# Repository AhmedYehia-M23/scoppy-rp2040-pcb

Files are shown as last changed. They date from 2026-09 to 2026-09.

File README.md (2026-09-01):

# Custom RP2040 Mixed-Signal Measurement PCB

**4-layer RP2040 hardware · KiCad · mixed-signal PCB layout · USB-C · hand assembly · hardware bring-up**

A university PCB-layout and hardware-bring-up project based on **professor-provided electrical schematics** for a custom RP2040 measurement board associated with the Scoppy oscilloscope ecosystem. My work was the **PCB implementation and physical hardware workflow**: placement, 4-layer stack-up and routing, fabrication preparation, hand assembly, bring-up and fault isolation.

| | |
|---|---|
| **Board** | 67 × 50 mm, 4 layers |
| **MCU** | RP2040 with W25Q128 QSPI flash |
| **Layout** | 64 footprints · 597 routed track segments · 58 vias |
| **Internal planes** | GND on In1.Cu · +3V3 on In2.Cu |
| **Academic context** | Materials and Manufacturing of Electronics · Summer Semester 2026 |

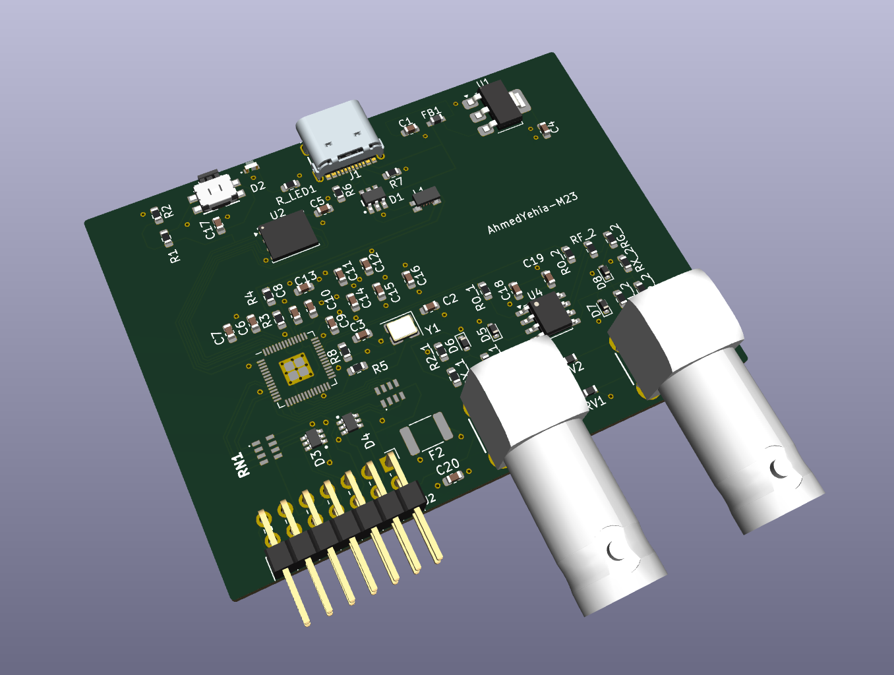
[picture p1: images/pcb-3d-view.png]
Scoppy RP2040 PCB 3D View


### Quick links

- [PCB layout source](hardware/Scoppy.kicad_pcb)
- [PCB layout image](images/pcb-layout.png)
- [Bring-up and debugging notes](docs/bring-up-and-debugging.md)
- [Source attribution](SOURCE_ATTRIBUTION.md)

> The electrical schematics and circuit/component-level design were supplied as course material. They are not redistributed here. The PCB placement, routing, assembly and bring-up documented in this repository are my project work.

## My contribution

- 4-layer PCB stack-up and physical implementation in KiCad
- complete component and footprint placement
- all PCB routing
- internal GND and +3V3 plane implementation
- mixed-signal physical-layout decisions
- board outline and physical organization
- design-rule checking and fabrication preparation
- complete hand assembly and soldering after fabrication
- board bring-up and electrical measurements
- USB-enumeration fault investigation
- power, continuity, USB, boot and clock checks
- root-cause isolation to incomplete RP2040 solder contact
- repair and restoration of USB enumeration

## PCB layout

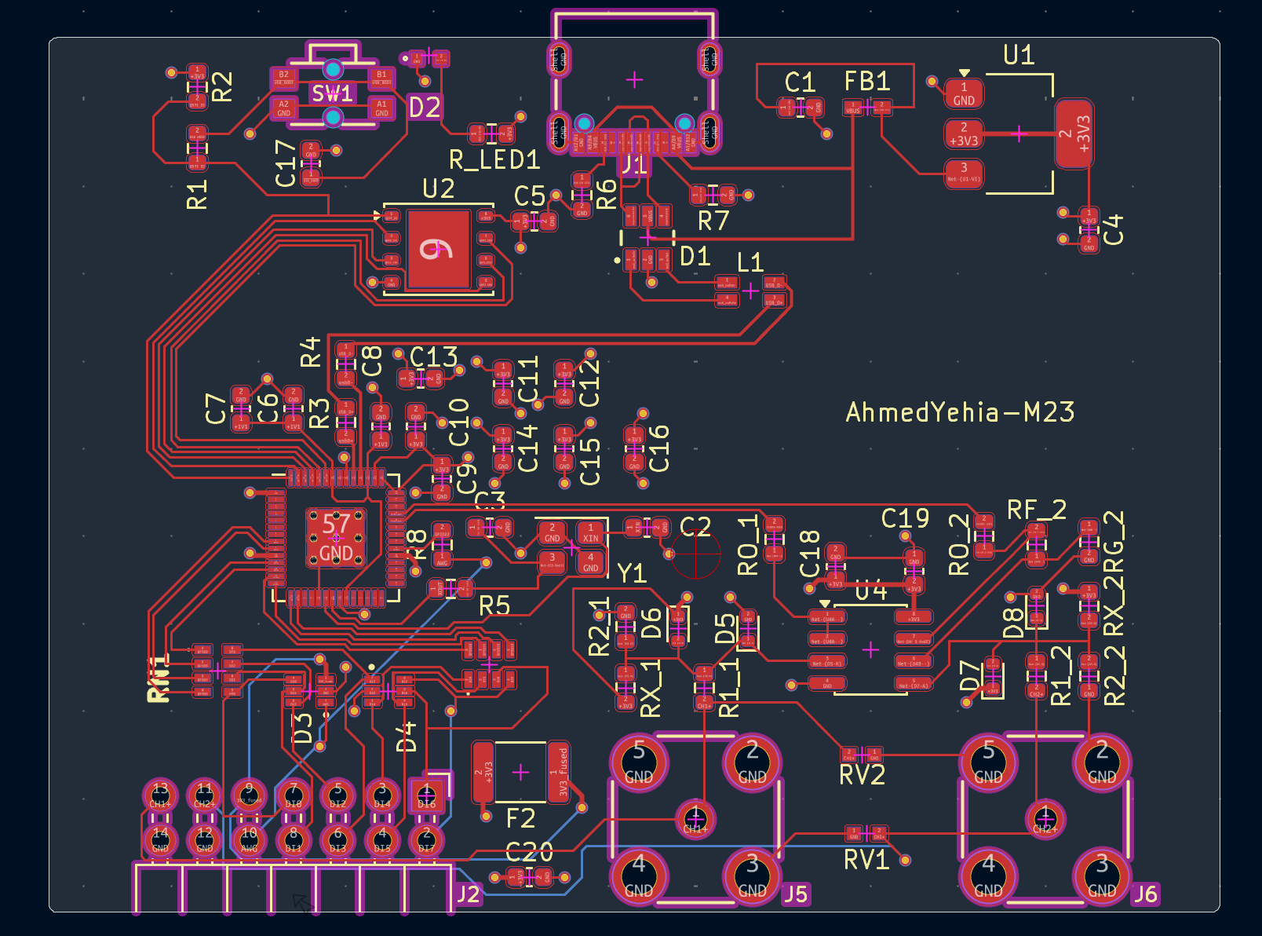
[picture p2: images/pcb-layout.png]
Scoppy RP2040 PCB Layout


## Architecture

Architecture

The supplied course design was organized into hierarchical **Power**, **Digital** and **Analog** schematic sheets. My task was to translate those circuit requirements into a manufacturable 4-layer PCB while managing placement, signal routing, return paths, power distribution and physical board constraints.

## Assembly and bring-up

After fabrication, I assembled and hand-soldered the complete board. The first assembled board powered up but failed to enumerate over USB, including BOOTSEL attempts.

The diagnostic sequence covered:

- 5 V, 3.3 V and RP2040 1.1 V rails
- RUN / BOOTSEL state
- external-flash related circuitry
- USB-C CC configuration
- D+ / D- continuity and short checks
- RP2040 grounding and exposed-pad contact
- 12 MHz crystal network
- physical MCU solder contact

The final root cause was incomplete electrical contact at the RP2040 package. Correcting the solder/contact defect **restored USB enumeration**.

The detailed check sequence and the boundary of the available evidence are documented in [`docs/bring-up-and-debugging.md`](docs/bring-up-and-debugging.md).

## Public project files

```text
hardware/
├── Scoppy.kicad_pro
├── Scoppy.kicad_pcb
├── fp-lib-table
└── LIB/
    └── footprints/
        └── DME_Template.pretty/

docs/
└── bring-up-and-debugging.md

images/
├── architecture.svg
├── pcb-layout.png
└── pcb-3d-view.png
```

Professor-provided schematic source and symbol/cache files are intentionally excluded from the public portfolio repository. Per-user KiCad state files, lock files, autosaves, backups and operating-system metadata are also excluded.

## Tools and skills

`KiCad` · `RP2040` · `4-Layer PCB Layout` · `Component Placement` · `Manual PCB Assembly & Soldering` · `Mixed-Signal PCB Routing` · `Internal Power/Ground Planes` · `USB-C` · `Hardware Bring-Up` · `Fault Isolation` · `Continuity & Voltage Measurement`

## Scoppy attribution

**Scoppy** is a separate project maintained by **fhdm-dev**. I did not develop the Scoppy Android application or its firmware. This repository presents my university PCB-layout, assembly and hardware-bring-up work and is not affiliated with or endorsed by the original Scoppy maintainers.

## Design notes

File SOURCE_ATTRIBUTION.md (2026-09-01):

# Source Attribution and Contribution Statement

## Electrical Schematics

The electrical schematics used for this university project were **provided by the professor as course/project material**. They defined the circuit and component-level electrical design that served as the input to the PCB-layout assignment.

The supplied material included the main schematic and hierarchical **Analog**, **Digital** and **Power** sheets.

I do **not** claim authorship of those electrical schematics. Their source files are intentionally **not redistributed in this public portfolio repository**.

## My Contribution

My individual engineering work on this project was the complete PCB implementation, physical board assembly and subsequent hardware bring-up, including:

- PCB stack-up and physical board implementation in KiCad
- Complete component and footprint placement
- **All routing of the 4-layer PCB**
- Internal power/ground plane implementation
- Mixed-signal layout and physical-routing decisions
- Board outline and physical organization
- Design-rule checking and layout preparation
- **Complete component assembly and hand-soldering after PCB fabrication**
- Board bring-up and electrical measurements
- USB-enumeration fault investigation
- Systematic power, continuity, USB, boot and clock checks
- Root-cause isolation to incomplete RP2040 solder contact
- Correction of the assembly defect and successful restoration of USB enumeration

The public source in this repository therefore focuses on my **PCB layout/implementation** and my own bring-up/debugging documentation rather than republishing the course-provided schematic source.

## Scoppy Attribution

The broader **Scoppy** oscilloscope/logic-analyzer ecosystem is a separate open-source project maintained by `fhdm-dev`:

https://github.com/fhdm-dev/scoppy

I did not develop the Scoppy Android application or its firmware. This repository documents my university PCB-layout, board-assembly/soldering and hardware-bring-up work for a custom RP2040 hardware implementation associated with that use case.

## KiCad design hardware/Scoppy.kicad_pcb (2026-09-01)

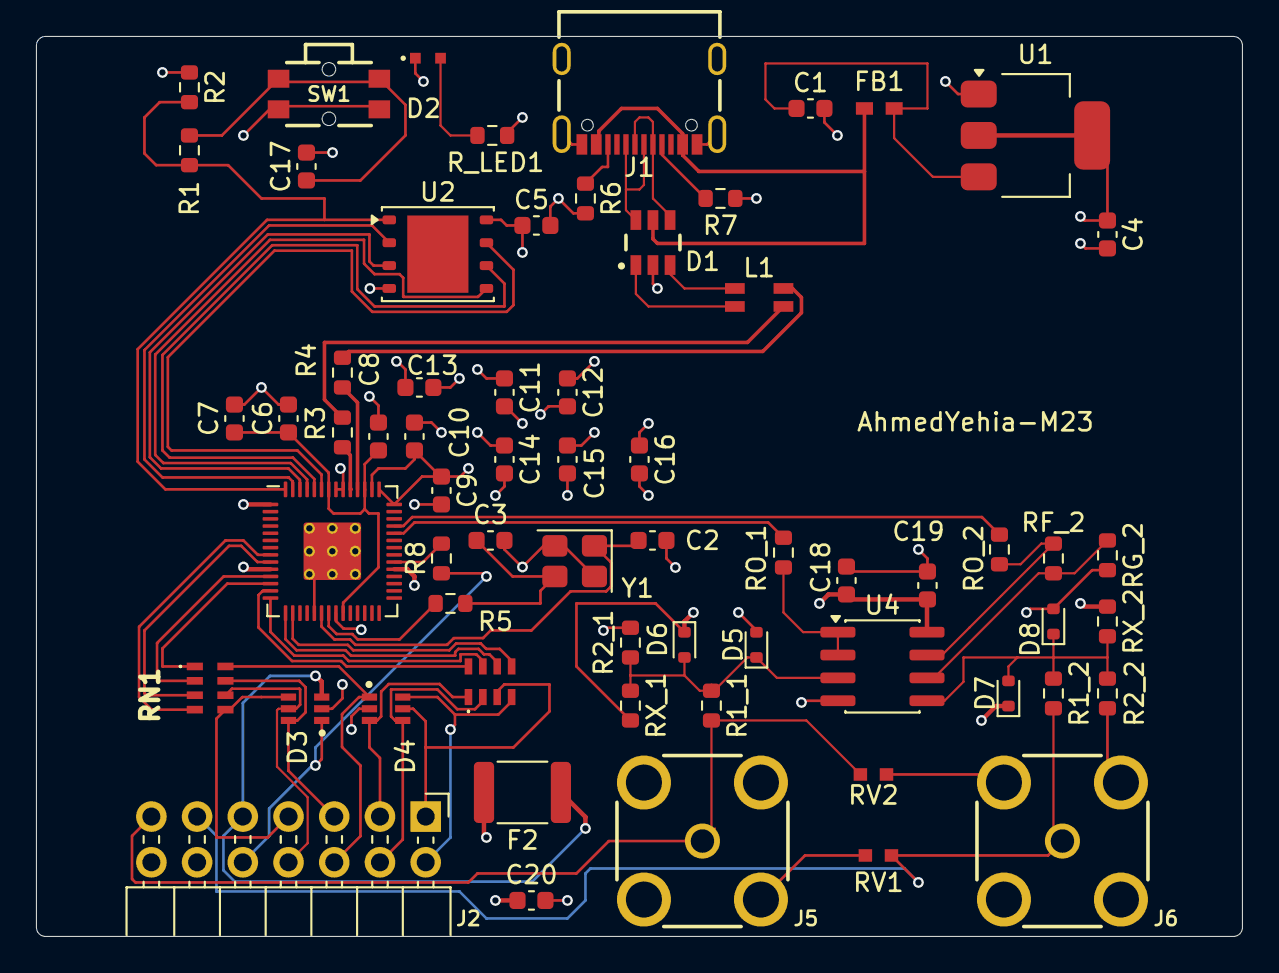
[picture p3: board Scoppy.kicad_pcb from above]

Board: 4 copper layers, 67.0 x 50.0 mm, 64 parts (0 on the bottom side), 54 nets.

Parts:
C1, C4: 10u; C_0603_1608Metric
C2, C3: 15p; C_0603_1608Metric
C5, C6, C7, C9, C11, C12, C13, C14, C15, C16, C17: 100n; C_0603_1608Metric
C8, C10: 1u; C_0603_1608Metric
C18: 10uf; C_0603_1608Metric
C19: 100nf; C_0603_1608Metric
C20: 22u; C_0603_1608Metric
D1: 5V; WE-TVS_SOT23-6L
D2: Bright Green, 2V, 140°; WL-SMSW_0603_L1.6W0.98H0.8
D3, D4: 5V; WE-TVS_SC70-6L
D5, D6, D7, D8: 1N4148; D_SOD-523
F2: 300mA PPTC; Fuse_1812_4532Metric
FB1: 600Ω; WE-CBF_0603_L1.6W0.8H0.8_HC
J1: 629722000214
J2: Conn_02x07_Odd_Even; PinHeader_2x07_P2.54mm_Horizontal
J5, J6: 60711002241501
L1: 90Ω @100MHz; WE-CNSW_1206
R1, R5: 1k; R_0603_1608Metric
R1_1, R2_1: 470k; R_0603_1608Metric
R1_2: 330k; R_0603_1608Metric
R2: 10k; R_0603_1608Metric
R2_2: 680k; R_0603_1608Metric
R3, R4: 27; R_0603_1608Metric
R6, R7: 5k1; R_0603_1608Metric
R8: 47; R_0603_1608Metric
RF_2: 18k; R_0603_1608Metric
RG_2: 10k; R_0603_1608Metric
RN1, RN2: CAY16-470J4LF; CAY16470J4LF
RO_1, RO_2: 100; R_0603_1608Metric
RV1, RV2: 12VDC, 5pF; WE-VE_0603
RX_1: 220k; R_0603_1608Metric
RX_2: 1M; R_0603_1608Metric
R_LED1: 1k; R_0603_1608Metric
SW1: 436351045816
U1: NCP1117-3.3_SOT223; SOT-223-3_TabPin2
U2: W25Q128JVS; WSON-8-1EP_6x5mm_P1.27mm_EP3.4x4.3mm
U3: RP2040; RP2040-QFN-56
U4: MCP6002-xSN; SOIC-8_3.9x4.9mm_P1.27mm
Y1: ABM8-272-T3; Crystal_SMD_3225-4Pin_3.2x2.5mm

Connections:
+1V1: C6.1, C7.1, C8.1, U3.23 (DVDD), U3.45 (VREG_VOUT), U3.50 (DVDD)
+3V3: C4.1, C5.1, C9.1, C10.1, C11.1, C12.1, C13.1, C14.1, C15.1, C16.1, C18.1, C19.2, C20.1, D6.1 (K), D7.1 (K), F2.2, R2.1, RX_1.2, RX_2.1, R_LED1.2, U1.2 (VO), U2.8 (VCC), U3.1 (IOVDD), U3.10 (IOVDD), U3.22 (IOVDD), U3.33 (IOVDD), U3.42 (IOVDD), U3.43 (ADC_AVDD), U3.44 (VREG_IN), U3.48 (USB_VDD), U3.49 (IOVDD), U4.8 (V+)
/Analog/CH1+: J2.13, J5.1 (Signal), R1_1.2, RV2.2
/Analog/CH2+: J2.11, J6.1 (Signal), R1_2.2, RV1.2
/Analog/GPIO26_ADC0: RO_1.2, U3.38 (GPIO26_ADC0)
/Analog/GPIO27_ADC1: RO_2.2, U3.39 (GPIO27_ADC1)
/Digital/3V3_fused: D3.3 (I/O_2), F2.1, J2.9
/Digital/AWG: D3.1 (I/O_1), J2.10, R8.1
/Digital/DI0: D3.4 (I/O_3), J2.7, RN1.5
/Digital/DI1: D3.5 (I/O_4), J2.8, RN1.6
/Digital/DI2: D3.6 (I/O_5), J2.5, RN1.7
/Digital/DI3: D4.1 (I/O_1), J2.6, RN1.8
/Digital/DI4: D4.3 (I/O_2), J2.3, RN2.1
/Digital/DI5: D4.4 (I/O_3), J2.4, RN2.2
/Digital/DI6: D4.5 (I/O_4), J2.1, RN2.3
/Digital/DI7: D4.6 (I/O_5), J2.2, RN2.4
/Digital/GPIO6: RN1.4, U3.8 (GPIO6)
/Digital/GPIO7: RN1.3, U3.9 (GPIO7)
/Digital/GPIO8: RN1.2, U3.11 (GPIO8)
/Digital/GPIO9: RN1.1, U3.12 (GPIO9)
/Digital/GPIO10: RN2.8, U3.13 (GPIO10)
/Digital/GPIO11: RN2.7, U3.14 (GPIO11)
/Digital/GPIO12: RN2.6, U3.15 (GPIO12)
/Digital/GPIO13: RN2.5, U3.16 (GPIO13)
/Digital/GPIO22: R8.2, U3.34 (GPIO22)
/Digital/QSPI_SCLK: U2.6 (CLK), U3.52 (QSPI_SCLK)
/Digital/QSPI_SD0: U2.5 (DI/IO_{0}), U3.53 (QSPI_SD0)
/Digital/QSPI_SD1: U2.2 (DO/IO_{1}), U3.55 (QSPI_SD1)
/Digital/QSPI_SD2: U2.3 (~WP/IO_{2}), U3.54 (QSPI_SD2)
/Digital/QSPI_SD3: U2.7 (~HOLD/~RESET/IO_{3}), U3.51 (QSPI_SD3)
/Digital/QSPI_SS: R1.1, R2.2, U2.1 (~CS), U3.56 (QSPI_SS)
/Digital/USB_D+: L1.3, R3.1
/Digital/USB_D-: L1.2, R4.1
/Digital/XIN: C2.1, U3.20 (XIN), Y1.1
/Digital/XOUT: R5.1, U3.21 (XOUT)
/Digital/usbD+: R3.2, U3.47 (USB_DP)
/Digital/usbD-: R4.2, U3.46 (USB_DM)
/Digital/~USB_BOOT: C17.1, R1.2, SW1.B1, SW1.B2
/Power/esd_safeD+: D1.1 (I/O_1), L1.4
/Power/esd_safeD-: D1.3 (I/O_2), L1.1
/Power/unprotectedD+: D1.6 (I/O_1), J1.A6 (D+1), J1.B6 (D+2)
/Power/unprotectedD-: D1.4 (I/O_2), J1.A7 (D-1), J1.B7 (D-2)
GND: C1.2, C2.2, C3.2, C4.2, C5.2, C6.2, C7.2, C8.2, C9.2, C10.2, C11.2, C12.2, C13.2, C14.2, C15.2, C16.2, C17.2, C18.2, C19.1, C20.2, D1.2 (GND), D2.1 (K), D3.2 (GND), D4.2 (GND), D5.2 (A), D8.2 (A), J1.A1/B12 (GND), J1.A12/B1 (GND), J1.Shell (Shield), J2.12, J2.14, J5.2 (GND), J5.3 (GND), J5.4 (GND), J5.5 (GND), J6.2 (GND), J6.3 (GND), J6.4 (GND), J6.5 (GND), R2_1.2, R2_2.1, R6.2, R7.2, RG_2.2, RV1.1, RV2.1, SW1.A1, SW1.A2, U1.1 (GND), U2.4 (GND), U3.19 (TESTEN), U3.57 (GND), U4.4 (V-), Y1.2, Y1.4
unnamed: C3.1, R5.2, Y1.3
unnamed: D2.2 (A), R_LED1.1
unnamed: D5.1 (K), D6.2 (A), R1_1.1, R2_1.1, RX_1.1, U4.3 (+)
unnamed: D7.2 (A), D8.1 (K), R1_2.1, R2_2.2, RX_2.2, U4.5 (+)
unnamed: J1.A5 (CC1), R7.1
unnamed: J1.B5 (CC2), R6.1
unnamed: RF_2.2, RO_2.1, U4.7
unnamed: C1.1, FB1.2, U1.3 (VI)
unnamed: RO_1.1, U4.1, U4.2 (-)
unnamed: RF_2.1, RG_2.1, U4.6 (-)
VBUS: D1.5 (VDD), FB1.1, J1.A4/B9 (VBUS), J1.A9/B4 (VBUS)

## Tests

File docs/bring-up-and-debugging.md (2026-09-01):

# Board Assembly, Bring-Up and USB Debugging

## Assembly

After PCB fabrication, I assembled and hand-soldered the complete board, including the RP2040, USB-C interface, external flash, power circuitry, analog-front-end parts and passives.

## Initial symptom

The board powered up but did **not enumerate as a USB device**, including attempts to enter BOOTSEL mode.

## Bring-up sequence

| Check | Result / conclusion |
| --- | --- |
| 5 V input rail | Present |
| 3.3 V rail | Present |
| RP2040 1.1 V core rail | Present |
| RUN / BOOTSEL state | Checked during fault isolation |
| External-flash related circuitry | Checked |
| USB-C CC configuration | Checked |
| D+ / D- path | Continuity checked through the USB interface path |
| D+ / D- short | No short identified during the checks |
| RP2040 grounding / exposed pad | Inspected |
| 12 MHz crystal network | Investigated as a possible USB-startup cause |
| Physical MCU solder contact | Fault found |

The troubleshooting order was deliberately **power first, then boot/reset state, USB connectivity, grounding, clock and finally package-level assembly inspection**.

## Isolation work

During the investigation I desoldered the USB connector to isolate the USB section and continue checking the board independently of the connector assembly.

## Root cause

The final fault was an **assembly/soldering defect at the RP2040**. The MCU was not making complete electrical contact with the PCB.

## Resolution

Correcting the RP2040 solder/contact problem restored **USB enumeration**.

The important result is therefore not just that the board eventually worked, but that the failure was reduced from a broad digital symptom — "USB not detected" — to a physical assembly defect using measurements and continuity checks rather than random component replacement.

## Evidence boundary

This repository documents the diagnostic sequence and the resolved fault. It does not currently include oscilloscope captures, exact measured rail values or a USB-enumeration screenshot from the original bring-up session, so none are reconstructed after the fact.

If the board is characterized again, useful additions would be:

- measured 5 V, 3.3 V and 1.1 V rail values
- 12 MHz oscillator capture
- BOOTSEL / USB-enumeration screenshot
- assembled-board photographs
- basic analog-input functional measurements

## Main takeaway

The project covered the complete physical PCB workflow:

**layout → fabrication → manual assembly → bring-up → measurement → fault isolation → repair**

It also reinforced a practical debugging rule: a high-level symptom such as failed USB enumeration can still originate from a basic package-level soldering fault.

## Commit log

2026-09-01 Initial release: Scoppy RP2040 PCB
    [Scoppy.kicad_pcb]
2026-09-01 Tighten bring-up notes
2026-09-01 Tighten project summary
